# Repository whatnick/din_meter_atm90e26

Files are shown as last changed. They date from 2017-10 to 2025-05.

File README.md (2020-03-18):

# DIN Rail / PCI-X1 compatible ATM90E26 Metering Module

This is a 2 unit DIN-Rail size in width ATM90E26 based metering module with a host of nice features, designed for use with the DIN-Rail energy monitor modules system.

## Features

- PCI-X1 lower connector for interface with power and analog voltage/current signals.
- x2 ATM90E26 energy monitor ASICs and associated crystals, RC filter networks.
- Molex SPI bus and power pass-through upper connector.
- Dense single-sided PCB with 0402 passives.
- Test points and jumpers on the bottom to allow additional uses.

## Renders

**DIN Meter ATM90E26 Front**
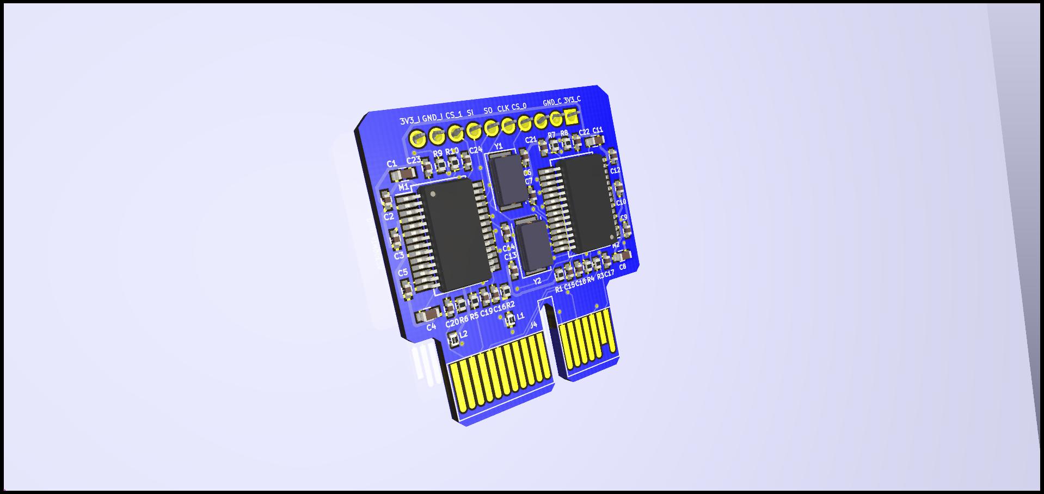
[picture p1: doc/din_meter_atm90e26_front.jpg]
meter front render


**DIN Meter ATM90E26 Back**
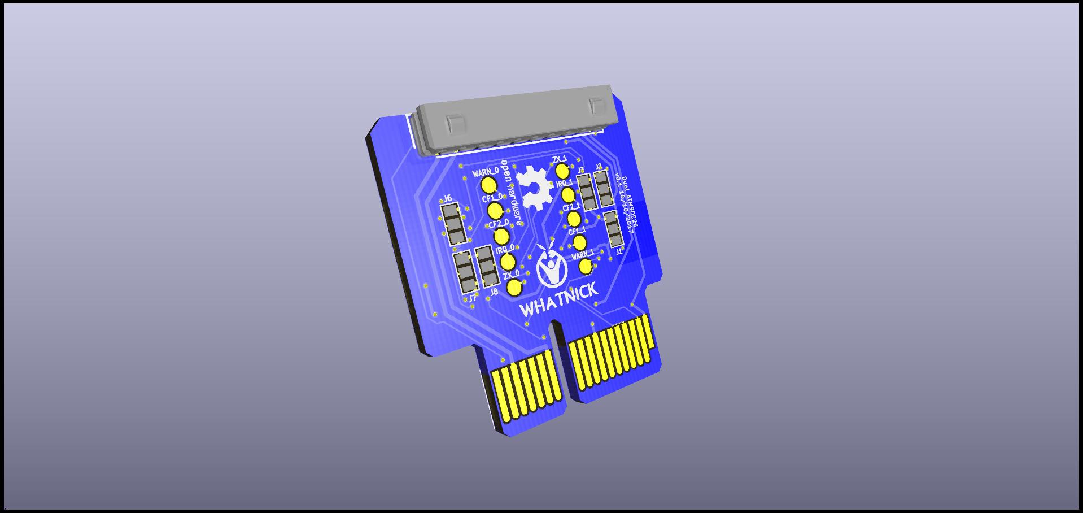
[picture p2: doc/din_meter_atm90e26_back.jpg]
meter back render


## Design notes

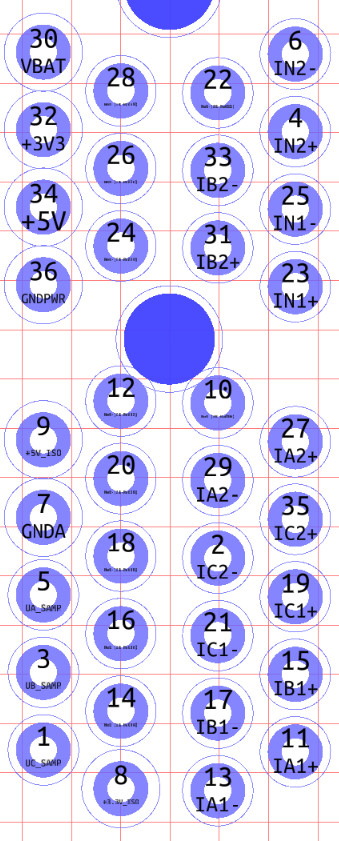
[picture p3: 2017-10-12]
doc/pci_x1_pinout.jpg

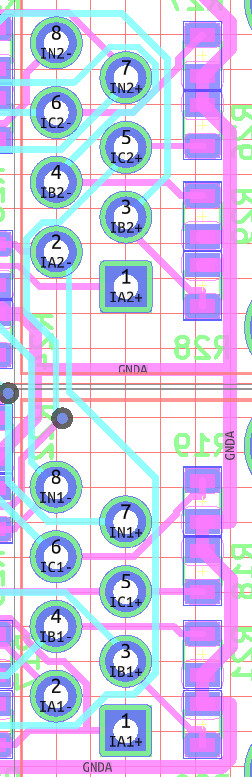
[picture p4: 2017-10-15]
doc/rj45_pinout.jpg

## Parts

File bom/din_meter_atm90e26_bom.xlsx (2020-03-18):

References | manf# | Value | Footprint | Quantity
C6, C7, C13, C14 | GRM1555C1H200JA01D | 20p | C_0402 | 4
C15, C16, C17, C18, C19, C20, C21, C22, C23, C24 | GRM155B11A333KA01D | 33n | C_0402 | 10
C2, C3, C5, C9, C10, C12 | GRM155R71C104KA88D | 100n | C_0402 | 6
C1, C4, C8, C11 | GRM188R61A106KE69D | 10u | C_0603 | 4
R1, R2, R3, R4, R5, R6, R7, R8, R9, R10 | CRCW04021K00FKED | 1K | R_0402 | 10
L1 | BLM15AG100SN1D | GND_SUP | L_0402 | 1
L2 | BLM15AG100SN1D | 3V3_SUP | L_0402 | 1
Y1, Y2 | AA-8.192MAGE-T | Crystal_Small | Crystal_SMD_5032-2pin_5.0x3.2mm | 2
M1, M2 | ATM90E26-YU-B | ATM90E26_ATM90E26 | SSOP-28_5.3x10.2mm_Pitch0.65mm | 2
J5 | 52418-1010 | CONN_01X10 | SHDR10W60P200_1X10_2150X400X335P | 1

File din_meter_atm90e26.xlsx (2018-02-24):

 |  |  |  |  |  |  | Board Qty: | 10
 |  |  |  |  |  |  | Total Cost: | $60.53 |  |  |  | $40.05 |  |  |  |  |  | $7.89 |  |  |  |  |  | $35.29 |  |  |  |  |  | $25.82 |  |  |  |  |  | $67.55
 |  |  |  |  |  |  | Unit Cost: | $6.05
Global Part Info |  |  |  |  |  |  |  |  | Digi-Key |  |  |  |  |  | Farnell |  |  |  |  |  | Mouser |  |  |  |  |  | Newark |  |  |  |  |  | Rs Components
Refs | Value | Desc | Footprint | Manf | Manf# | Qty | Unit$ | Ext$ | Avail | Purch | Unit$ | Ext$ | Cat# | Doc | Avail | Purch | Unit$ | Ext$ | Cat# | Doc | Avail | Purch | Unit$ | Ext$ | Cat# | Doc | Avail | Purch | Unit$ | Ext$ | Cat# | Doc | Avail | Purch | Unit$ | Ext$ | Cat# | Doc
M1,M2 | ATM90E26_ATM90E26 |  | Housings_SSOP:SSOP-28_5.3x10.2mm_Pitch0.65mm |  | ATM90E26-YU-B | 20 | $0.94 | $18.86 | 16092 |  | $0.97 | $19.40 | ATM90E26-YU-B-ND | Link (http://www.digikey.com/scripts/DkSearch/dksus.dll?WT.z_header=search_go&lang=en) |  |  |  |  |  |  | 2539 |  | $0.94 | $18.86 | 556-ATM90E26-YU-B | Link (http://www.mouser.com/Search/Refine.aspx?Keyword=ATM90E26-YU-B%20) |  |  | $1.01 | $20.20 | 67X3998 | Link (http://www.newark.com/webapp/wcs/stores/servlet/Search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) | 2130 |  | $1.19 | $23.80 | 127-8222 | Link (http://it.rs-online.com/web/c/?searchTerm=ATM90E26-YU-B%20)
C2,C3,C5,C9,C10,C12 | 100n |  | Capacitors_SMD:C_0402 |  | GCM155R71C104KA55D | 60 | $0.01 | $0.42 | 53233587 |  | $0.01 | $0.84 | 490-3261-1-ND | Link (http://www.digikey.com/product-detail/en/murata-electronics-north-america/GRM155R71C104KA88D/490-3261-1-ND/702802) |  |  | $0.02 | $0.92 | 8819742 | Link (http://it.farnell.com/murata/grm155r71c104ka88d/condensatore-mlcc-x7r-100nf-16v/dp/8819742) | 1204290 |  | $0.01 | $0.42 | 81-GRM155R71C104KA88 | Link (http://www.mouser.com/Search/Refine.aspx?Keyword=GRM155R71C104KA88D%20) |  |  | $0.01 | $0.42 | 38K1647 | Link (http://www.newark.com/murata/grm155r71c104ka88d/ceramic-capacitor-0-1uf-16v-x7r/dp/38K1647) | 4800 |  | $0.02 | $1.07 | 723-5228 | Link (http://it.rs-online.com/web/c/?searchTerm=GRM155R71C104KA88D%20)
C1,C4,C8,C11 | 10u |  | Capacitors_SMD:C_0603 |  | GRM188R61A106KE69D | 40 | $0.07 | $2.66 |  |  | $0.15 | $5.84 | 490-10474-1-ND | Link (http://www.digikey.com/product-detail/en/murata-electronics-north-america/GRM188R61A106KE69D/490-10474-1-ND/5026392) |  |  | $0.09 | $3.43 | 2494233 | Link (http://it.farnell.com/murata/grm188r61a106ke69d/condensatore-mlcc-x5r-10uf-10v/dp/2494233) |  |  | $0.08 | $3.20 | 81-GRM188R61A106KE9D | Link (http://www.mouser.com/ProductDetail/Murata-Electronics/GRM188R61A106KE69D/) |  |  | $0.07 | $2.88 | 55Y9855 | Link (http://www.newark.com/murata/grm188r61a106ke69d/smd-multilayer-ceramic-capacitor/dp/55Y9855) | 10400 |  | $0.07 | $2.66 | 846-7293 | Link (http://it.rs-online.com/web/c/?searchTerm=GRM188R61A106KE69D%20)
Y1,Y2 | Crystal_Small |  | Crystals:Crystal_SMD_5032-2pin_5.0x3.2mm |  | AA-8.192MAGE-T | 20 | $1.59 | $31.82 |  |  |  |  |  |  |  |  |  |  |  |  |  |  |  |  |  |  |  |  |  |  |  |  | 165 |  | $1.59 | $31.82 | 810-2514 | Link (http://it.rs-online.com/web/c/?searchTerm=5XFA08192123TF80Q3%20)
C6,C7,C13,C14 | 20p |  | Capacitors_SMD:C_0402 |  | GRM1555C1H200JA01D | 40 | $0.01 | $0.29 | 3178007 |  | $0.02 | $0.76 | 490-5930-1-ND | Link (http://www.digikey.com/product-detail/en/murata-electronics-north-america/GRM1555C1H200JA01D/490-5930-1-ND/3721287) |  |  | $0.01 | $0.60 | 2218848 | Link (http://it.farnell.com/murata/grm1555c1h200ja01d/condens-mlcc-c0g-np0-20pf-50v/dp/2218848) | 623286 |  | $0.01 | $0.44 | 81-GRM1555C1H200JA1D | Link (http://www.mouser.com/Search/Refine.aspx?Keyword=GRM1555C1H200JA01D%20) |  |  | $0.01 | $0.36 | 48W5744 | Link (http://www.newark.com/webapp/wcs/stores/servlet/Search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) | 500 |  | $0.01 | $0.29 | 814-5561 | Link (http://it.rs-online.com/web/c/?searchTerm=GRM1555C1H200JA01D%20)
J5 | CONN_01X10 |  | 52418-1010:SHDR10W60P200_1X10_2150X400X335P |  | 52418-1010 | 10 | $0.48 | $4.84 | 1156 |  | $1.02 | $10.20 | WM6478-ND | Link (http://www.digikey.com/scripts/DkSearch/dksus.dll?WT.z_header=search_go&lang=en) |  |  |  |  |  |  | 5369 |  | $0.84 | $8.41 | 538-52418-1010 | Link (http://www.mouser.com/Search/Refine.aspx?Keyword=52418-1010%20) |  |  |  |  |  |  | 610 |  | $0.48 | $4.84 | 720-6283 | Link (http://it.rs-online.com/web/c/?searchTerm=52418-1010%20)
R1,R2,R3,R4,R5,R6,R7,R8,R9,R10 | 1K |  | Resistors_SMD:R_0402 |  | WR04X1001FTL | 100 | $0.01 | $0.60 |  |  | $0.01 | $1.49 | 541-1.00KLCT-ND | Link (http://www.digikey.com/product-detail/en/vishay-dale/CRCW04021K00FKED/541-1.00KLCT-ND/1183123) |  |  | $0.02 | $2.14 | 1469662 | Link (http://it.farnell.com/vishay/crcw04021k00fked/res-film-spesso-1k-1-0-063w-0402/dp/1469662) |  |  | $0.03 | $2.60 | 71-CRCW0402-1.0K-E3 | Link (http://www.mouser.com/ProductDetail/Vishay/CRCW04021K00FKED/?qs=sGAEpiMZZMu61qfTUdNhG2DpbjADlD3GFJ4zSbeLqG8%3D) |  |  | $0.01 | $0.60 | 19K7992 | Link (http://www.newark.com/vishay/crcw04021k00fked/res-thick-film-1k-1-0-063w-0402/dp/19K7992) | 12850 |  | $0.02 | $2.02 | 678-8872 | Link (http://it.rs-online.com/web/p/resistori-smd/6788872/)
C15,C16,C17,C18,C19,C20,C21,C22,C23,C24 | 33n |  | Capacitors_SMD:C_0402 |  | TMK105BJ333KV-F | 100 | $0.004756 | $0.48 |  |  |  |  |  |  |  |  |  |  |  |  |  |  |  |  | Not Assigned | Link (http://www.mouser.com/Search/Refine.aspx?Keyword=GRM155B11A333KA01D%20) |  |  |  |  |  |  | 8750 |  | $0.004756 | $0.48 | 798-6885 | Link (http://it.rs-online.com/web/c/?searchTerm=GRM155B11A333KA01D%20)
L1 | GND_SUP |  | Inductors_SMD:L_0402 |  | BLM15AG100SN1D | 10 | $0.03 | $0.29 | 87568 |  | $0.08 | $0.76 | 490-5176-1-ND | Link (http://www.digikey.com/product-detail/en/murata-electronics-north-america/BLM15AG100SN1D/490-5176-1-ND/1948352) |  |  | $0.04 | $0.40 | 1515758 | Link (http://it.farnell.com/murata/blm15ag100sn1d/grano-chip-0-05ohm-1a-0402/dp/1515758) | 14397 |  | $0.07 | $0.68 | 81-BLM15AG100SN1D | Link (http://www.mouser.com/Search/Refine.aspx?Keyword=BLM15AG100SN1D%20) |  |  | $0.07 | $0.68 | 73M9021 | Link (http://www.newark.com/webapp/wcs/stores/servlet/Search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) | 5725 |  | $0.03 | $0.29 | 110-756 | Link (http://it.rs-online.com/web/p/ferriti/0110756/)
L2 | 3V3_SUP |  | Inductors_SMD:L_0402 |  | BLM15AG100SN1D | 10 | $0.03 | $0.29 | 87568 |  | $0.08 | $0.76 | 490-5176-1-ND | Link (http://www.digikey.com/product-detail/en/murata-electronics-north-america/BLM15AG100SN1D/490-5176-1-ND/1948352) |  |  | $0.04 | $0.40 | 1515758 | Link (http://it.farnell.com/murata/blm15ag100sn1d/grano-chip-0-05ohm-1a-0402/dp/1515758) | 14397 |  | $0.07 | $0.68 | 81-BLM15AG100SN1D | Link (http://www.mouser.com/Search/Refine.aspx?Keyword=BLM15AG100SN1D%20) |  |  | $0.07 | $0.68 | 73M9021 | Link (http://www.newark.com/webapp/wcs/stores/servlet/Search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) | 5725 |  | $0.03 | $0.29 | 110-756 | Link (http://it.rs-online.com/web/p/ferriti/0110756/)

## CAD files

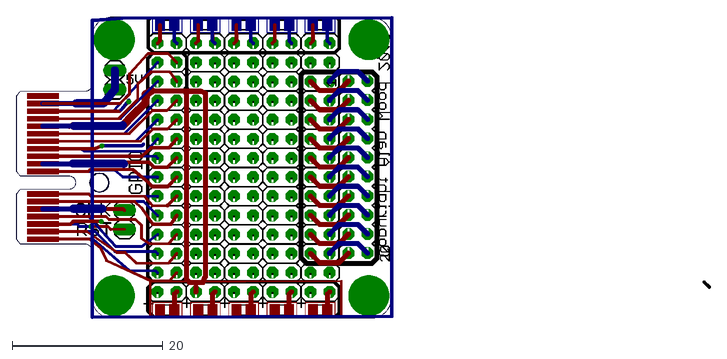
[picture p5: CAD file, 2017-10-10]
patchslice.dxf
92.2 x 40.2

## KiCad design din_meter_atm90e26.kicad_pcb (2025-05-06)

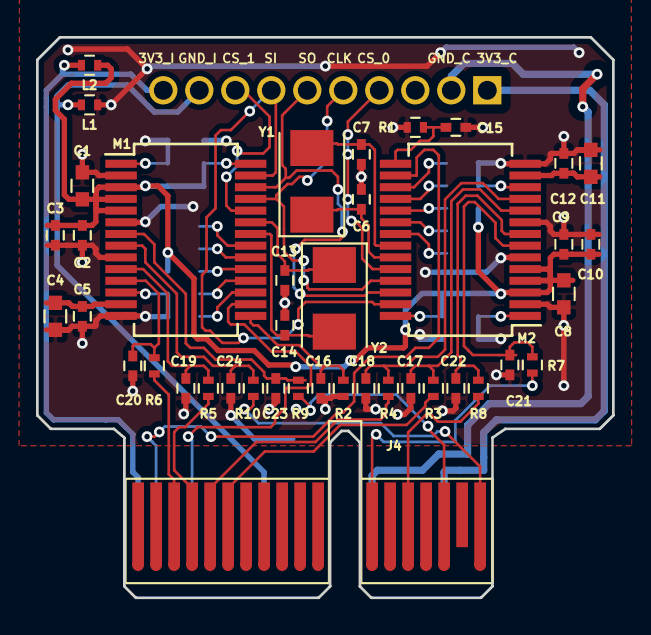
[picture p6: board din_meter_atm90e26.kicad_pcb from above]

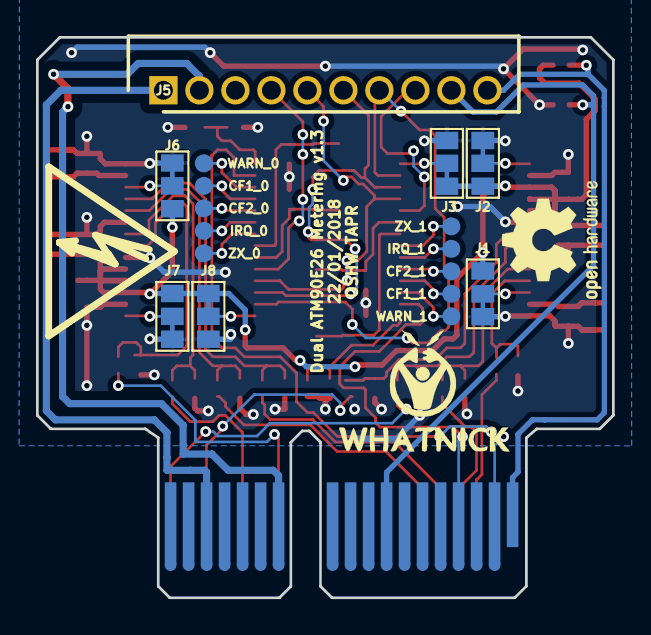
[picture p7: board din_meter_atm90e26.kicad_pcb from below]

Board: 2 copper layers, 32.0 x 31.1 mm, 61 parts (20 on the bottom side), 53 nets.

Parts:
C1, C4, C8, C11: 10u; C_0603
C2, C3, C5, C9, C10, C12: 100n; C_0402
C6, C7, C13, C14: 20p; C_0402
C15, C16, C17, C18, C19, C20, C21, C22, C23, C24: 33n; C_0402
CF1_0: CF1_0; Measurement_Point_Round-SMD-Pad_Small
CF1_1: CF1_1; Measurement_Point_Round-SMD-Pad_Small
CF2_0: CF2_0; Measurement_Point_Round-SMD-Pad_Small
CF2_1: CF2_1; Measurement_Point_Round-SMD-Pad_Small
G1: LOGO; Whatnick_logo
IRQ_0: IRQ_0; Measurement_Point_Round-SMD-Pad_Small
IRQ_1: IRQ_1; Measurement_Point_Round-SMD-Pad_Small
J1, J6: USEL; GS3
J2, J7: MMD1; GS3
J3, J8: MMD0; GS3
J4: CONN_02X18; PCI-EXPRESS
J5: CONN_01X10; SHDR10W60P200_1X10_2150X400X335P
L1: GND_SUP; L_0402
L2: 3V3_SUP; L_0402
LOGO1: Logo_Open_Hardware_Small; OSHW-Logo2_7.3x6mm_SilkScreen
M1, M2: ATM90E26_ATM90E26; SSOP-28_5.3x10.2mm_Pitch0.65mm
R1, R2, R3, R4, R5, R6, R7, R8, R9, R10: 1K; R_0402
SYM1: SYM_Flash_Small; Fsilk_HV
WARN_0: WARN_0; Measurement_Point_Round-SMD-Pad_Small
WARN_1: WARN_1; Measurement_Point_Round-SMD-Pad_Small
Y1, Y2: Crystal_Small; Crystal_SMD_5032-2pin_5.0x3.2mm
ZX_0: ZX_0; Measurement_Point_Round-SMD-Pad_Small
ZX_1: ZX_1; Measurement_Point_Round-SMD-Pad_Small

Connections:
3V3_CPU: J4.A16, J5.1
3V3_ISO: J4.A1, J5.10, L2.1
+3V3: C1.1, C2.2, C3.1, C8.1, C9.2, C10.1, J1.3, J2.3, J3.1, J6.3, J7.3, J8.1, L2.2, M1.3, M1.4, M1.5, M2.3, M2.4, M2.5
CF1_0: CF1_0.1, M2.18
CF1_1: CF1_1.1, M1.18
CF2_0: CF2_0.1, M2.19
CF2_1: CF2_1.1, M1.19
CLKIN_0: C7.2, M2.22, Y1.2
CLKIN_1: C14.2, M1.22, Y2.2
CLKOUT_0: C6.2, M2.23, Y1.1
CLKOUT_1: C13.2, M1.23, Y2.1
CS_0: J5.4, M2.24
CS_1: J5.8, M1.24
GNDD: C1.2, C2.1, C3.2, C4.2, C5.2, C6.1, C7.1, C8.2, C9.1, C10.2, C11.2, C12.2, C13.1, C14.1, C15.1, C16.1, C17.1, C18.1, C19.1, C20.1, C21.1, C22.1, C23.1, C24.1, J1.1, J2.1, J3.3, J6.1, J7.1, J8.3, L1.2, M1.2, M1.6, M1.9, M1.14, M2.2, M2.6, M2.9, M2.14, R1.2, R2.2
GND_CPU: J4.A12, J5.2
GND_ISO: J4.A8, J5.9, L1.1
I1N_0: C18.2, M2.11, R4.1
I1N_0_IN: J4.B5, R4.2
I1N_1: C20.2, M1.11, R6.1
I1N_1_IN: J4.B3, R6.2
I1P_0: C17.2, M2.10, R3.1
I1P_0_IN: J4.B6, R3.2
I1P_1: C19.2, M1.10, R5.1
I1P_1_IN: J4.B4, R5.2
I2N_0: C22.2, M2.8, R8.1
I2N_0_IN: J4.B14, R8.2
I2N_1: C24.2, M1.8, R10.1
I2N_1_IN: J4.B18, R10.2
I2P_0: C21.2, M2.7, R7.1
I2P_0_IN: J4.B12, R7.2
I2P_1: C23.2, M1.7, R9.1
I2P_1_IN: J4.B16, R9.2
IRQ_0: IRQ_0.1, M2.20
IRQ_1: IRQ_1.1, M1.20
unnamed: C4.1, C5.1, M1.13
unnamed: C11.1, C12.1, M2.13
unnamed: J1.2, M1.12
unnamed: J2.2, M1.1
unnamed: J3.2, M1.28
unnamed: J6.2, M2.12
unnamed: J7.2, M2.1
unnamed: J8.2, M2.28
SCLK: J5.5, M1.25, M2.25
SI/RX: J5.7, M1.27, M2.27
SO/TX: J5.6, M1.26, M2.26
VN_0: C15.2, M2.15, R1.1
VN_1: C16.2, M1.15, R2.1
VP_0: J4.A2, M2.16
VP_1: J4.A4, M1.16
WARN_0: M2.17, WARN_0.1
WARN_1: M1.17, WARN_1.1
ZX_0: M2.21, ZX_0.1
ZX_1: M1.21, ZX_1.1

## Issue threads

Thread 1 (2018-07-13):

Add complete ESP32 support

ammaree, 2018-07-13:
Hi Tisham,

As discussed it would be of great value to add comprehensive support to expand the isolated SPI mezzanine board to support the additional pins on the ESP32 based (Wemos) Mini D1 modules.

Specifically add support for the zero crossing warning and interrupt signals from the M90Ex6 chips. If this can be done separately for each channel, great. If not signals can be combined (per channel or per type) to minimize the additional pins required.

I understand that this will also affect the M90E26 and M90E36 metering boards (risers) but considering the additional power and functionality of the ESP32 modules, I believe this will be the platform of choice going forward

Thanks

whatnick, 2020-12-22:
I am a few years too late in responding to this. However I will note that these signals are already exposed via test points. The best backward compatible change to this system will be to convert these test points into an SMD high density ( JST-SH or Molex Picoblade) connector and send the additional signals via a cable to an ESP32 specific host / mezzanine board.

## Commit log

2017-10-07 Initial import
    [_saved_din_meter_atm90e26.sch, din_meter_atm90e26.kicad_pcb, din_meter_atm90e26.sch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]
2017-10-10 Full import
    [_saved_din_meter_atm90e26.sch, patchslice.dxf, protoslice.dsn]
2017-10-11 Initial place and route without PCI-E connector
    [din_meter_atm90e26.dsn, din_meter_atm90e26.kicad_pcb, din_meter_atm90e26.sch]
2017-10-12 Renumber PCI-X
    [din_meter_atm90e26.kicad_pcb, din_meter_atm90e26.sch]
2017-10-13 Add labels to PCI-X
    [din_meter_atm90e26.kicad_pcb, din_meter_atm90e26.sch]
2017-10-15 v0.1 prepped for fab
    [din_meter_atm90e26-B.Cu.gbl, din_meter_atm90e26-B.Mask.gbs, din_meter_atm90e26-B.Paste.gbp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]
2017-10-16 Update dimension
    [din_meter_atm90e26.kicad_pcb]
2017-10-16 Moved some tracks up to reduce exposure, updated screenshots
    [din_meter_atm90e26.kicad_pcb]
2017-10-16 Moved some tracks up to reduce exposure
    [din_meter_atm90e26.kicad_pcb]
2017-10-23 Update BOM
    [din_meter_atm90e26.sch, din_meter_atm90e26.xlsx]
2017-11-20 Rerouted board from joslyn
    [din_meter_atm90e26.kicad_pcb]
2017-11-22 Add back logos and bump version
    [din_meter_atm90e26.kicad_pcb, din_meter_atm90e26.sch]
2017-11-22 New gerbers
    [din_meter_atm90e26-B.Cu.gbl, din_meter_atm90e26-B.Mask.gbs, din_meter_atm90e26-B.Paste.gbp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]
2017-11-22 Update gerbers and dimensions
    [din_meter_atm90e26.kicad_pcb]
2017-11-22 Update gerbers
    [din_meter_atm90e26-B.Cu.gbl, din_meter_atm90e26-B.Mask.gbs, din_meter_atm90e26-B.Paste.gbp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]
2017-12-07 Bump version and close jumpers using traces
    [din_meter_atm90e26.kicad_pcb]
2018-01-22 Open soldermask on gold fingers and bump version
    [din_meter_atm90e26.kicad_pcb, din_meter_atm90e26.sch]
2018-01-22 Fab layers to get dims
    [din_meter_atm90e26.kicad_pcb]
2018-01-22 added tapr licence on silk
    [din_meter_atm90e26.kicad_pcb]
2018-01-22 New gerbers with silk and vias on pads fixes
    [din_meter_atm90e26-B.Cu.gbl, din_meter_atm90e26-B.Mask.gbs, din_meter_atm90e26-B.Paste.gbp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]
2018-01-22 Fix vias on pads
    [din_meter_atm90e26-B.Cu.gbl, din_meter_atm90e26-B.Mask.gbs, din_meter_atm90e26-B.Paste.gbp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]
2018-02-24 Update BOM for use with Macrofab
    [din_meter_atm90e26.xlsx]
2020-03-16 Migrate to KiCAD v5.0
    [din_meter_atm90e26-2020-03-16-22-55-34.sch, din_meter_atm90e26.kicad_pcb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]
2020-03-18 New gerbers and gitignore
    [din_meter_atm90e26-B_Cu.gbl, din_meter_atm90e26-B_Mask.gbs, din_meter_atm90e26-B_Paste.gbp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]
2020-03-18 Remove ignored files
    [din_meter_atm90e26.dsn, protoslice.dsn]
2020-03-18 Add excel BOM
    [din_meter_atm90e26_bom.xlsx]
2020-12-23 Remove protoslice stuff
    [protoslice.kicad_pcb]
2025-05-06 Upgrade to KiCAD 7.0
    [din_meter_atm90e26.kicad_pcb]
